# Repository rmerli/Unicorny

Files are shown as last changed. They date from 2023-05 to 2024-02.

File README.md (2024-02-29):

# Unicorny
It is a unibody ergonomic keyboard inspired by the ferris-sweep (34 keys).
The aim of this keyboard is to have a layout as close as possbile to the ferris-sweep but in a unibody frame, 
to improve connection stability and because I found it easier to carry around.

## Features
- Wired/wireless
- Hotswap choc v1
- ProMicro footprint (designed with ninenano v2 in mind)
- Oled screen (optional)
- Power Switch (Wireless)

## Firmware
I choose Zmk and the config can be found [here](https://github.com/Riccardo-merli94/zmk/tree/main/app/boards/shields/unicorny).
I built the firmware locally, so the repository contains a fork of zmk, if you want to build it using the github actions, you'll need to follow the zmk doc.
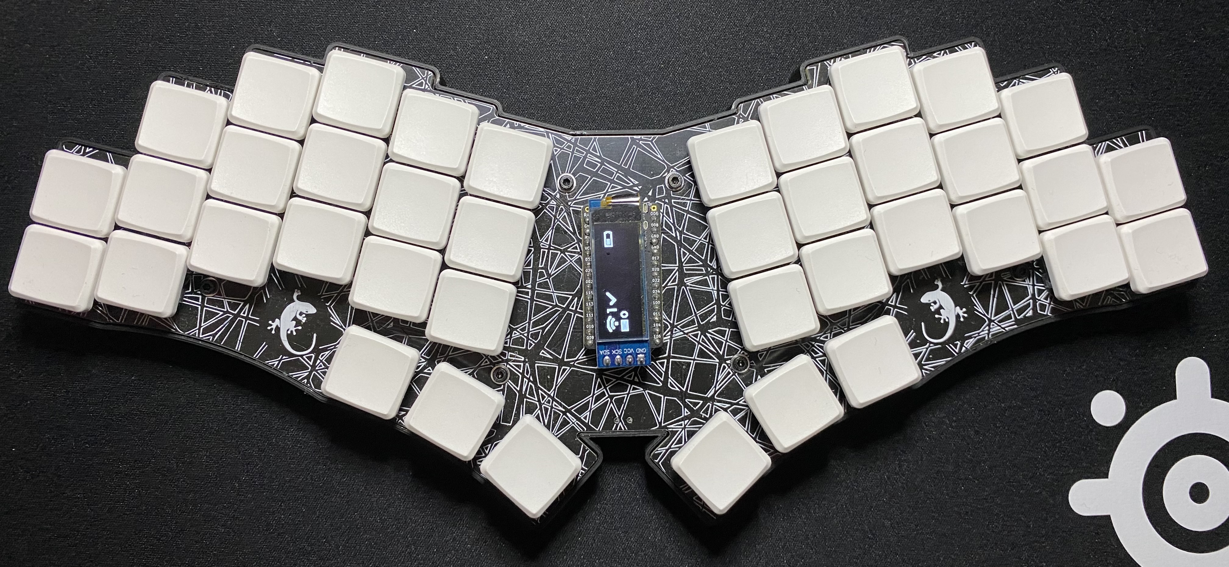
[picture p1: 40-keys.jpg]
unicorny-40

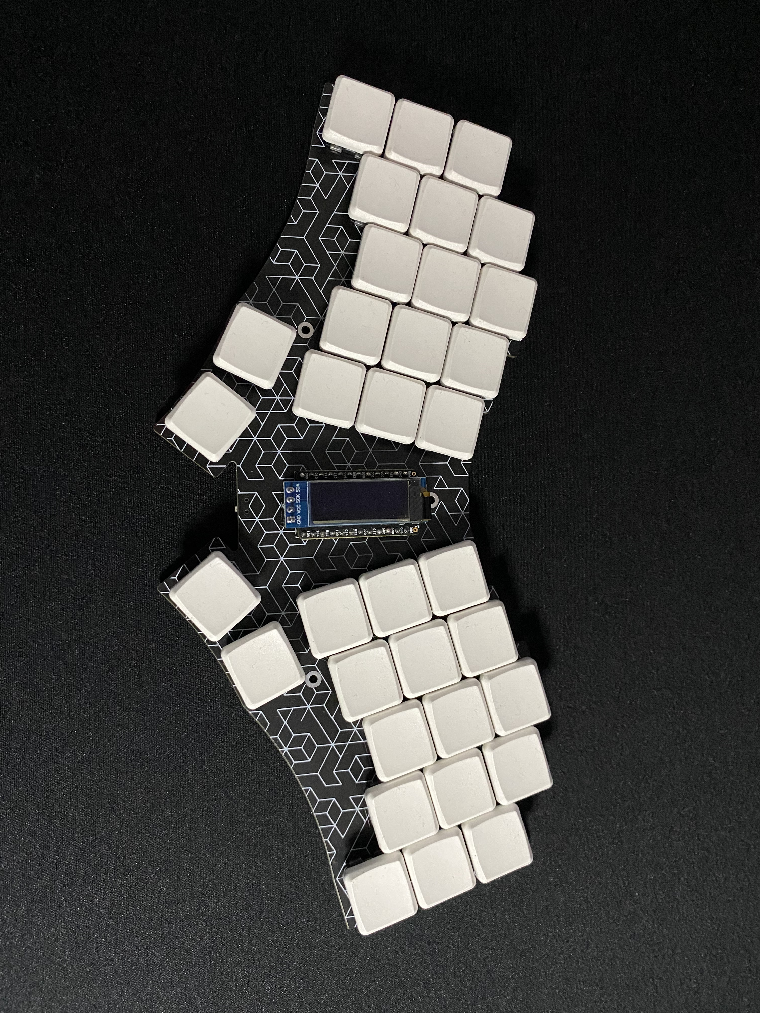
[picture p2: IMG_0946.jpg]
unicorny


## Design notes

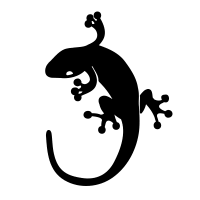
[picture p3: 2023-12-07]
Kicad_40/images/images.png

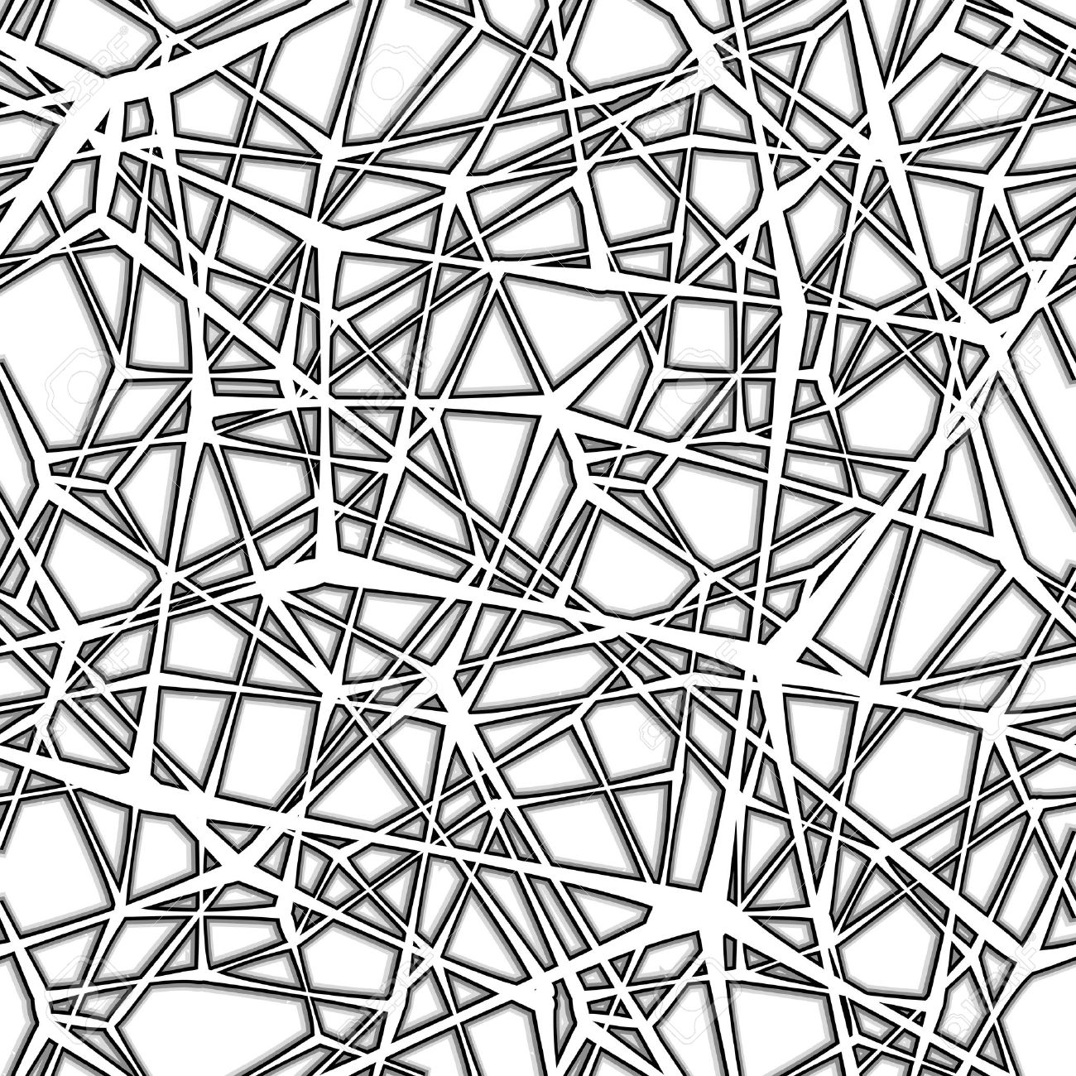
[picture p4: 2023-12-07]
Kicad_40/images/Pattern.jpg

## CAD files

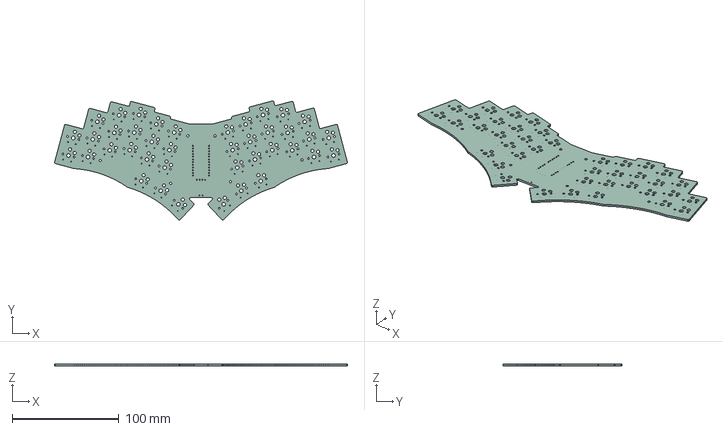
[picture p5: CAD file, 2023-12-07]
Kicad_40/oled_unicorny.step
274.5 x 111.7 x 1.60 mm

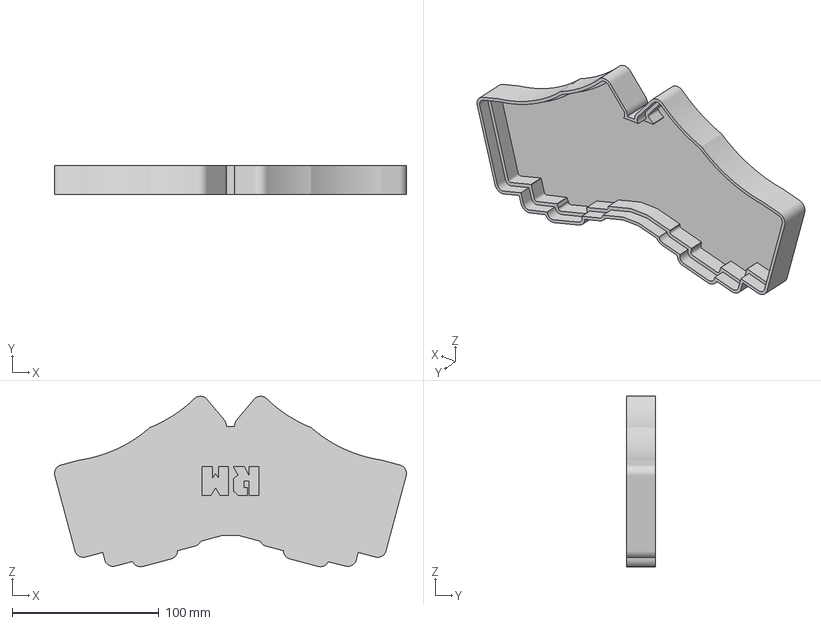
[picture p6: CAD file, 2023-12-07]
Stl/Cover.3mf
239.6 x 20.0 x 116.1 mm

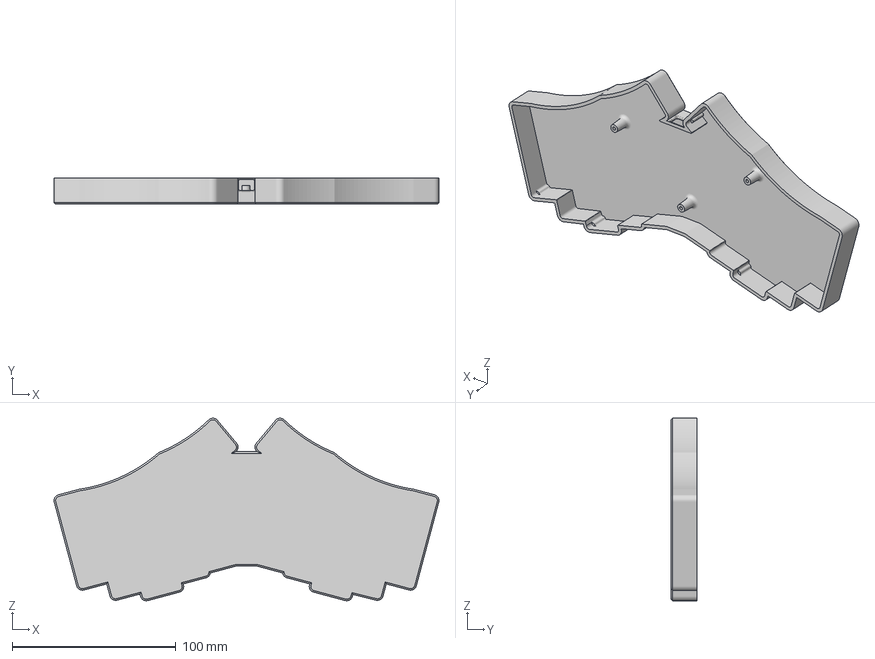
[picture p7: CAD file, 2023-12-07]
Stl/Case.3mf
235.0 x 16.1 x 111.5 mm

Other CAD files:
Unicorny v3.f3d

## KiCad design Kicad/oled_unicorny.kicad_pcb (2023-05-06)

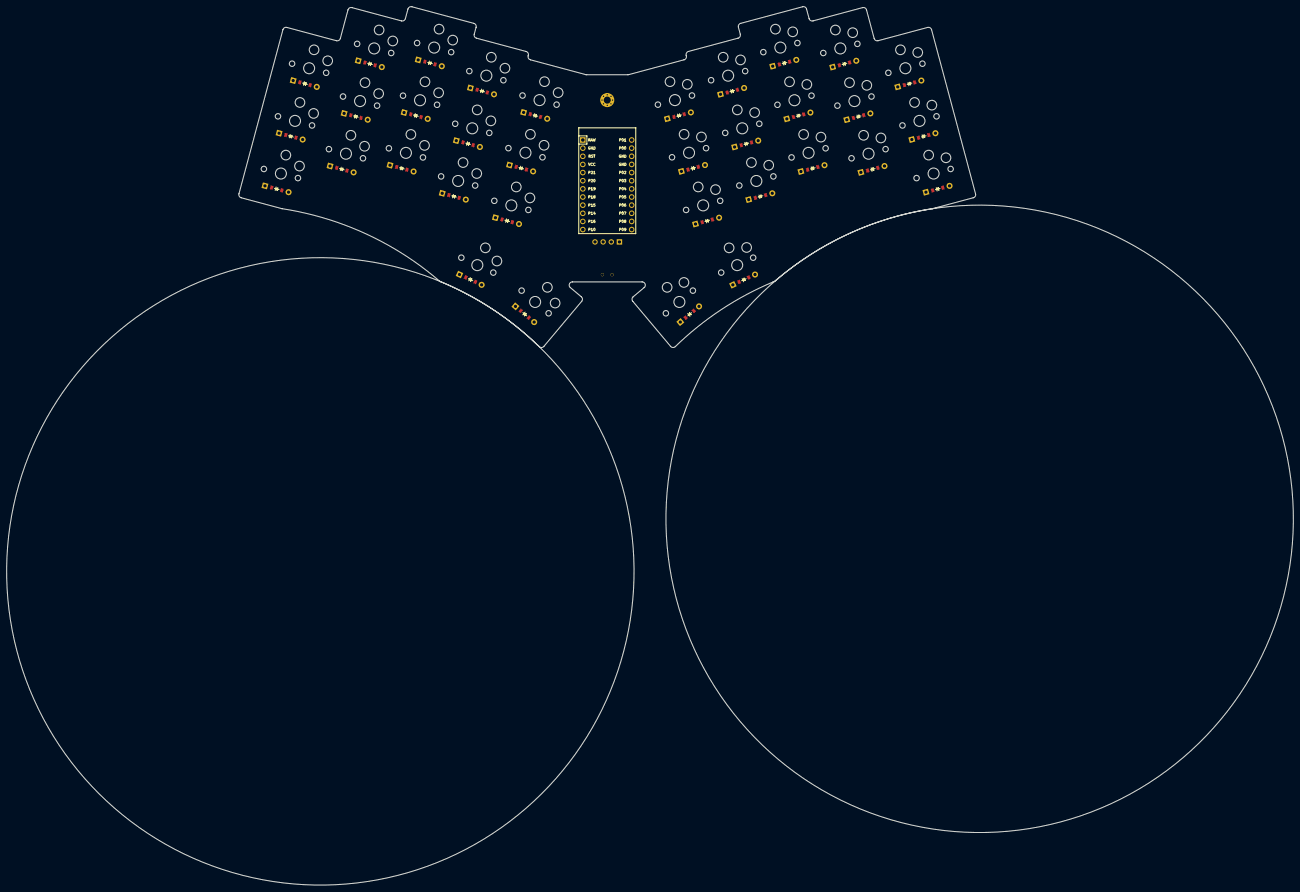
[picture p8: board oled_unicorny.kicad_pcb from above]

Board: 2 copper layers, 401.3 x 274.0 mm, 74 parts (0 on the bottom side), 52 nets, no tracks yet.

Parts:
D1, D2, D3, D4, D5, D6, D7, D8, D9, D10, D11, D12, D13, D14, D15, D16, D17, D18, D19, D20, D21, D22, D23, D24, D25, D26, D27, D28, D29, D30, D31, D32, D33, D34: ComboDiode
MCU1: ProMicro
OLED1: OLED; OLED_headers
PAD1, PAD2: SMDPad
S1, S2, S3, S4, S5, S6, S7, S8, S9, S10, S11, S12, S13, S14, S15, S16, S17, S18, S19, S20, S21, S22, S23, S24, S25, S26, S27, S28, S29, S30, S31, S32, S33, S34: PG1350
T1: SPDT_C128955
_1: MountingHole_2.2mm_M2_Pad_Via

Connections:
B+: PAD1.1, T1.2
GND: MCU1.2, MCU1.15, MCU1.16, OLED1.1, PAD2.1
P0: MCU1.14, S10.1, S11.1, S12.1, S16.1, S27.1, S28.1, S29.1, S33.1
P1: MCU1.13, S13.1, S14.1, S15.1, S17.1, S30.1, S31.1, S32.1, S34.1
P2: MCU1.17, OLED1.4
P3: MCU1.18, OLED1.3
P6: D20.1, D23.1, D26.1, D29.1, D32.1, MCU1.21
P7: D19.1, D22.1, D25.1, D28.1, D31.1, MCU1.22
P8: D18.1, D21.1, D24.1, D27.1, D30.1, MCU1.23
P14: D1.1, D4.1, D7.1, D10.1, D13.1, MCU1.10
P15: D2.1, D5.1, D8.1, D11.1, D14.1, MCU1.9
P16: D16.1, D17.1, D33.1, D34.1, MCU1.11
P18: D3.1, D6.1, D9.1, D12.1, D15.1, MCU1.8
P19: MCU1.7, S1.1, S2.1, S3.1, S18.1, S19.1, S20.1
P20: MCU1.6, S4.1, S5.1, S6.1, S21.1, S22.1, S23.1
P21: MCU1.5, S7.1, S8.1, S9.1, S24.1, S25.1, S26.1
RAW: MCU1.1, T1.1
VCC: MCU1.4, OLED1.2
index_bottom: D10.2, S10.2
index_home: D11.2, S11.2
index_top: D12.2, S12.2
inner_bottom: D13.2, S13.2
inner_home: D14.2, S14.2
inner_top: D15.2, S15.2
middle_bottom: D7.2, S7.2
middle_home: D8.2, S8.2
middle_top: D9.2, S9.2
mirror_index_bottom: D27.2, S27.2
mirror_index_home: D28.2, S28.2
mirror_index_top: D29.2, S29.2
mirror_inner_bottom: D30.2, S30.2
mirror_inner_home: D31.2, S31.2
mirror_inner_top: D32.2, S32.2
mirror_middle_bottom: D24.2, S24.2
mirror_middle_home: D25.2, S25.2
mirror_middle_top: D26.2, S26.2
mirror_pinky_bottom: D18.2, S18.2
mirror_pinky_home: D19.2, S19.2
mirror_pinky_top: D20.2, S20.2
mirror_reachy_fan: D34.2, S34.2
mirror_ring_bottom: D21.2, S21.2
mirror_ring_home: D22.2, S22.2
mirror_ring_top: D23.2, S23.2
mirror_tucky_fan: D33.2, S33.2
pinky_bottom: D1.2, S1.2
pinky_home: D2.2, S2.2
pinky_top: D3.2, S3.2
reachy_fan: D17.2, S17.2
ring_bottom: D4.2, S4.2
ring_home: D5.2, S5.2
ring_top: D6.2, S6.2
tucky_fan: D16.2, S16.2

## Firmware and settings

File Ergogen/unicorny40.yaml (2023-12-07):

units:
  kx: cx
  ky: cy

  px: kx + 2
  py: ky + 2

points:
  zones:
    matrix:
      anchor:
        shift: [100, -100]
      key: 
        padding: 1ky
        spread: 1kx
      columns:
        shifty:
          key:
            column_net: P5
          rows: 
            top:
               skip: true
        pinky:
          key:
            column_net: P19
            stagger: 0.20ky
        ring:
          key:
            stagger: 0.66ky
            column_net: P20
        middle:
          key:
            stagger: 0.30ky
            column_net: P21
        index:
          key:
            stagger: -0.25ky
            column_net: P0
        inner:
          key:
            stagger: -0.18ky
            column_net: P1
      rows:
        bottom:
          padding: ky
          row_net: P14
          mirror.row_net: P8
        home:
          padding: ky
          row_net: P15
          mirror.row_net: P7
        top:
          padding: ky
          row_net: P18
          mirror.row_net: P6
    thumb:
      anchor:
        ref: matrix_index_bottom
        shift: [0U, -1.1U]
        rotate: -8
      columns:
        tucky:
          key:
            name: thumb_tucky
            column_net: P21    
        middy:
          key:
            spread: U
            splay: -8
            origin: [-0.5U, -0.5U]
            name: thumb_middy
            column_net: P0
        reachy:
          key:
            spread: U
            splay: -12
            origin: [-0.5U, -0.5U]
            name: thumb_reachy
            column_net: P1
      rows:
        fan:
          row_net: P16
          mirror.row_net: P9
  rotate: -15
  mirror: &mirror
    ref: thumb_reachy
    distance: 2.35kx
outlines:

  raw:
    - what: rectangle
      where: true
      size: [px+2, py+2]

  keys:
    - what: rectangle
      where: true
      size: [kx-0.5,ky-0.5]



  pinky_add_left:
    - what: polygon
      operation: stack
      points:
        - ref: matrix_middle_bottom
          shift: [0px,-1.5ky]
        - ref: matrix_middle_bottom
          shift: [0.5px,-2ky]
        - ref: matrix_pinky_bottom
          shift: [-0.5kx  ,-0.5ky - 0.2ky -2]
        - ref: matrix_pinky_bottom
          shift: [-0.5kx ,-0.5ky] 
  pinky_add_right:
    - what: polygon
      operation: stack
      points:
        - ref: mirror_matrix_middle_bottom
          shift: [0px,-1.5ky]
        - ref: mirror_matrix_middle_bottom
          shift: [0.5px,-2ky]
        - ref: mirror_matrix_pinky_bottom
          shift: [-0.5kx  ,-0.5ky - 0.2ky -2]
        - ref: mirror_matrix_pinky_bottom
          shift: [-0.5kx ,-0.5ky]

  pinky_add:
    - name: pinky_add_left
    - operation: 
      name: pinky_add_right

  circle_left_main:
    - what: circle
      operation: stack
      where: 
        - ref: matrix_middle_bottom
          shift: [ -1.32px,-6.7py]
      radius: 5.21py
  circle_left_sub:
    - what: circle
      operation: stack
      where: 
        - ref: matrix_middle_bottom
          shift: [ 5.26,-7py]
      radius: 5.2py
  circle_left:
    - name: circle_left_main
    - operation: 
      name: circle_left_sub



  circle_right_main:
    - what: circle
      operation: stack
      where: 
        - ref: mirror_matrix_middle_bottom
          shift: [ -1.32px,-6.7py]
      radius: 5.21py
  circle_right_sub:
    - what: circle
      operation: stack
      where: 
        - ref: mirror_matrix_middle_bottom
          shift: [ 5.26,-7py]
      radius: 5.2py
  circle_right:
    - name: circle_right_main
    - operation: 
      name: circle_right_sub



  circle_complete:
    - name: circle_left
    - operation: 
      name: circle_right
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

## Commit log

2023-11-25 added 40 keys variant
    [Unicorny_40.kicad_pcb, Unicorny_40.kicad_sch]
2023-12-07 added board cad file
    [oled_unicorny.step]
2023-12-07 added stls and f360 project
    [Case.3mf, Cover.3mf, Unicorny v3.f3d]
